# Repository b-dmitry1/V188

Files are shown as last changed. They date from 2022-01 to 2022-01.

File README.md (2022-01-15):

# V188

FPGA 80186 IBM PC compatible system for Altera Cyclone IV (EP4CE15F23/EP4CE55F23).

* Compact CPU implementation (CPU can fit in 1500-2300 LEs and 4-6 M9K ROM blocks!).
* Easy-to-understand extensible FPGA-accelerated microcode.
* Inexpensive 4-layer PCB.
* A minimal set of inexpensive external components is required. All the electronic components can be easily found on AliExpress or eBay.
* Can be used with lower capacity FPGA devices if you don't need music in games.
* Up to 50 MHz input clock speed.

The CPU is a simple **stack virtual machine** with a specialized reduced instruction set.

Execution algorithm:

1. The VM fetches an opcode from system memory pointed by CS:IP.
2. There is a table of instruction code locations at the beginning of a microcode file. Using a loaded opcode value the VM starts processing microcode by table-jumping.
3. VM emulates real CPU behavior by sequentially executing microcode instructions.
4. When END microcode instruction is executed VM resets temporary state registers and instruction prefixes, checks pending interrupt requests, and repeats the algorithm from step 1.

Microcode example for table translation (XLAT) instruction:

```assembly
; xlat
LOADREG BX      ; Push BX register into VM stack
LOADREG8 AL     ; Push AL register into VM stack
ADD             ; Add two values on the top of VM stack and push back the result
SETOFS          ; Save value on the top of VM stack as a memory address (offset)
READ8           ; Read 8-bit value from system RAM pointed by the data segment register
                ; and an address saved in a previous instruction
                ; Data segment register is DS unless overridden by instruction prefix
STOREREG8 AL    ; Save the result into AL register
END             ; Go to a next instruction
```

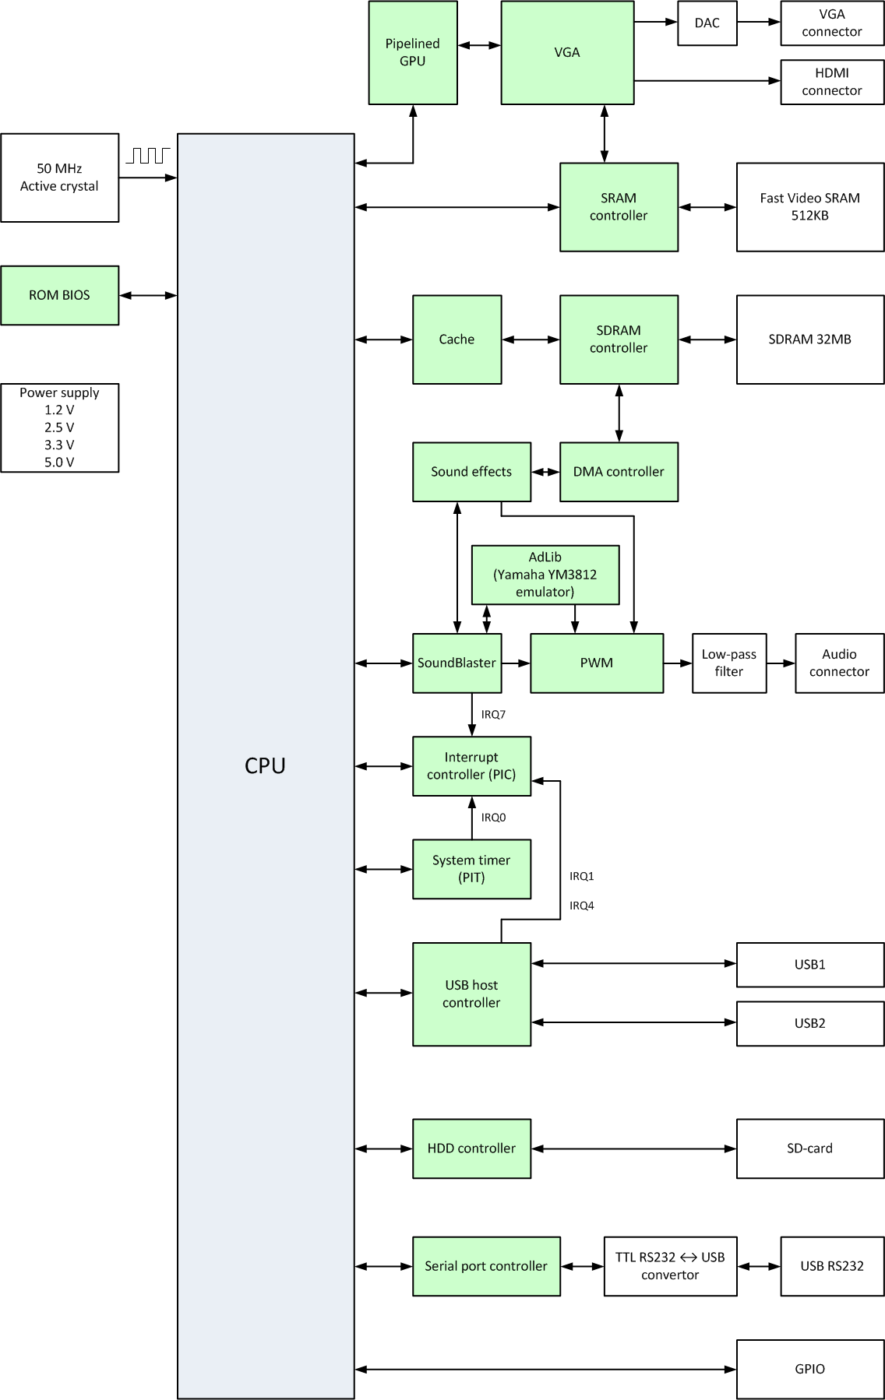
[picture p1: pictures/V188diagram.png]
V188 diagram


To play Dune 2 and Wolfenstein 3D just enable 286 CPU detection in the mcode.asm file:

    %define SHOW_8086

Comment this line, compile and update the project firmware. This line should be uncommented if you want to run Windows or Minix in 16-bit real mode.

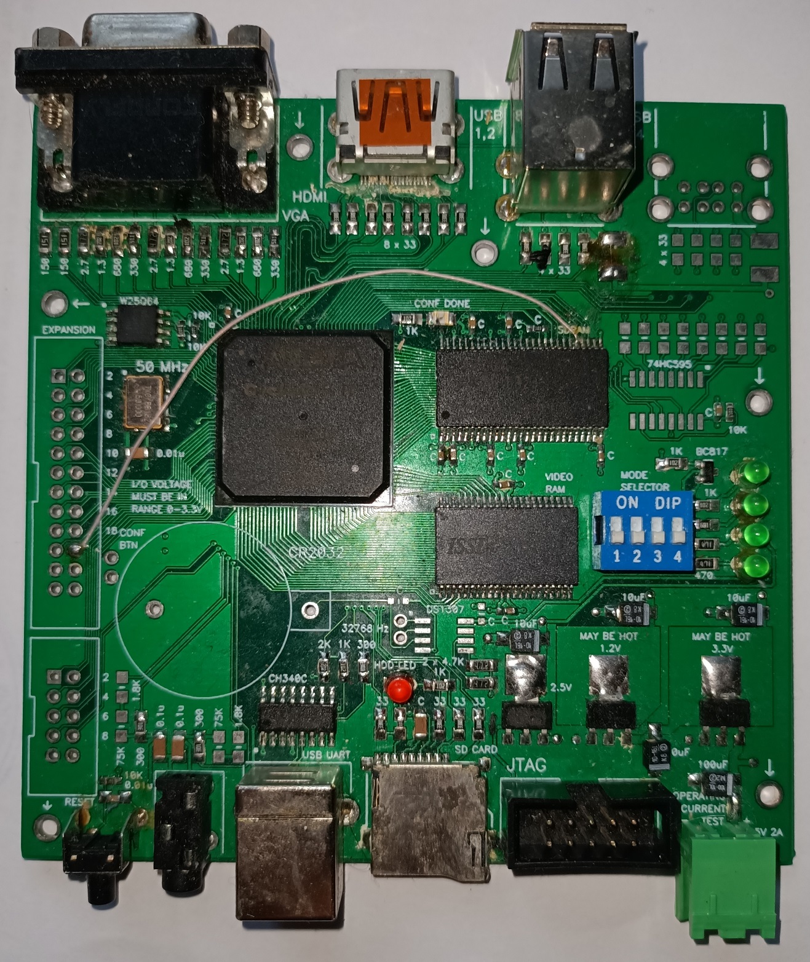
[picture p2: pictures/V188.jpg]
V188


## Printed circuit board (PCB)

PCB Gerber files can be found in a [Gerber directory](Gerber/).

## BIOS

Please use this compact BIOS:

<https://github.com/b-dmitry1/BIOS>

## VGA

* CGA/EGA/VGA video card emulation.
* Linear / Planar addressing support.
* Simple EGA/VGA graphics processor (pipeline) compatible with most old games and Microsoft Windows.
* Planar 320x240x256 colors (mode X) support.
* 2 x 64-bit GPU data buses designed to unload RAM controller.
* The framebuffer can be located in the main system memory or in a dedicated video RAM.

## SoundBlaster

* 8-bit digital sound effects with DMA support.
* Unprecise but very simple extensible AdLib emulation.
* High-quality PWM output requires only 1-2 resistors and 1 ceramic capacitor.

AdLib consumes a lot of FPGA resources. Precise YM3812 emulation may require 30K LEs or even more.

## SDRAM controller

* Very simple and compact finite state machine design.
* Multiple channels. Additional channels can be easily added.
* Channel priorites defined by their order.
* Different bus widths.
* Automatic SDRAM refresh.
* Designed for a low-cost 16/32 megabyte SDRAM ICs.

## Memory card interface

Up to 32GB memory card with SPI support can be used.

Only 504 MB will be available due to 16-bit BIOS's limitations.

## USB

This version contains a new USB module with a dedicated parallel processing core designed to operate independently from a main CPU.
Firmware for this fast module is not completed.
Please use an old implementation from deprecated/USB folder or a Serial Port as a keyboard.

There are 4 USB ports on the board.
In this version only 2 low-speed ports are available.
The first one should be used for a keyboard and the second one for mouse.

USB needs a special BIOS driver to work properly.

## Compiling

Please use Quartus 13.0sp1 to compile the project.

To compile from a command line use "compile.bat" script.

## Disk images

Images from [e86r project](https://github.com/b-dmitry1/e86r) will work good.

Just write an 504 MB image on an SD card as described in the STM32 section of e86r.

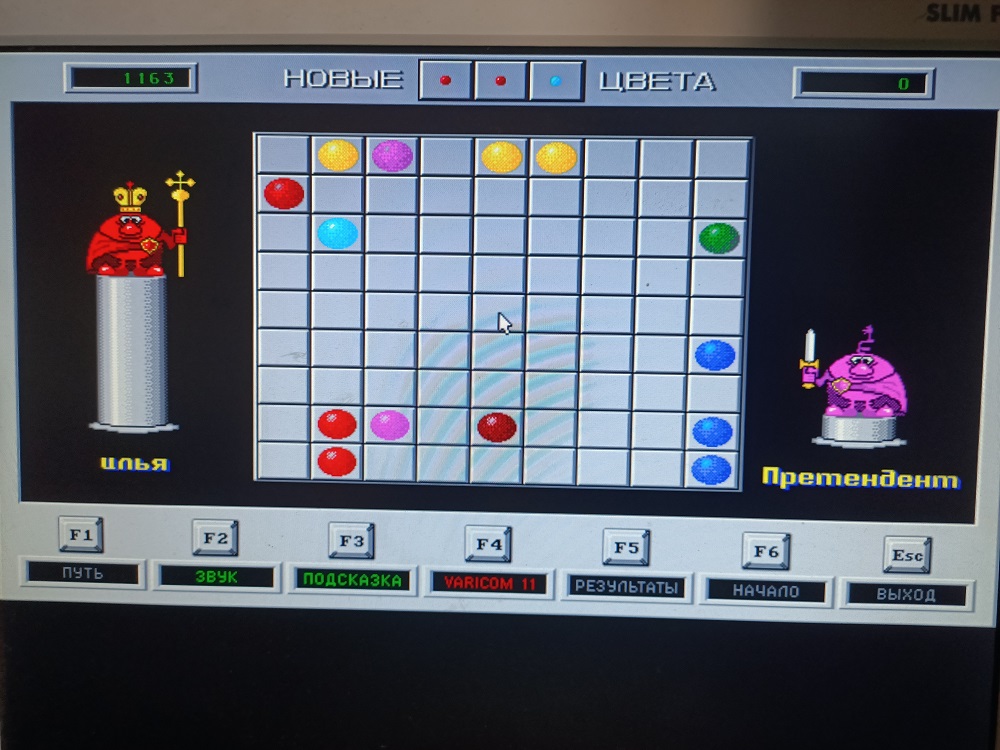
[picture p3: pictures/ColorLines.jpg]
Lines game screenshot


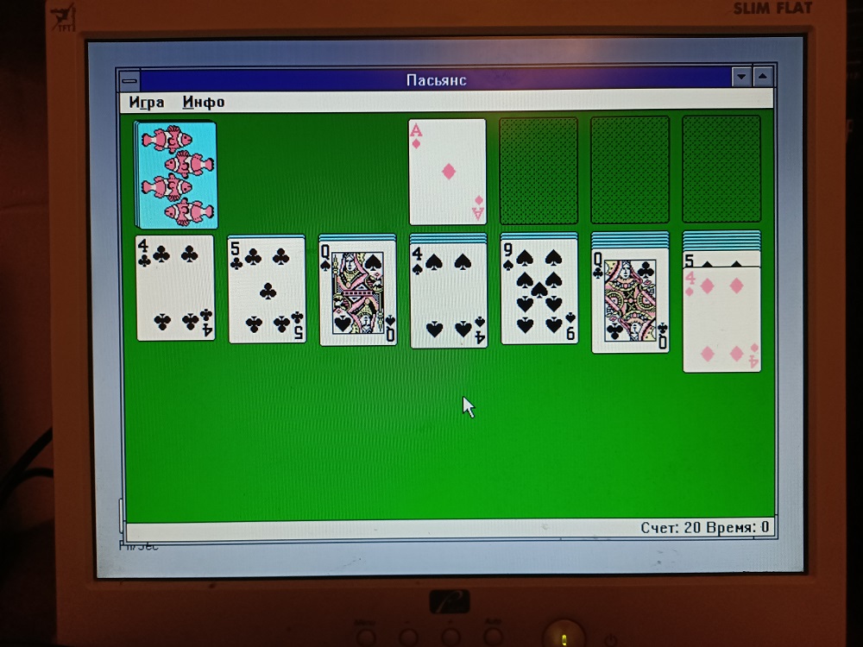
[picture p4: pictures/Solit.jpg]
Solitare game screenshot


## Known problems

* USB detection / hot plugging sometimes fails.
* USB port 1 supports only a keyboard and port 2 supports only a mouse. (BIOS problem)
* Only low-speed USB device support.
* VGA virtual resolution (panning) calculation may be wrong for some games.
* No FPU emulation.

## Disclaimer

The project is provided "as is" without any warranty. Use at your own risk.

Please contact me if you find any bug or if you plan to port it to another platform.

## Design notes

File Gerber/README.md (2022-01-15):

# V188 Gerber files

This folder contains Gerber PCB files of the board.

Technology:

* 4 layers.
* Minimum hole diameter is 0.3 mm.
* Via diameter is 0.6 mm.
* Track width min 0.127 mm.
* Track-to-pad min 0.127 mm.
* Track-to-track min 0.127 mm.

Most popular PCB factories should accept it without applying a price multiplier.

I have paid only $7 for 5 pcs on jlcpcb.com

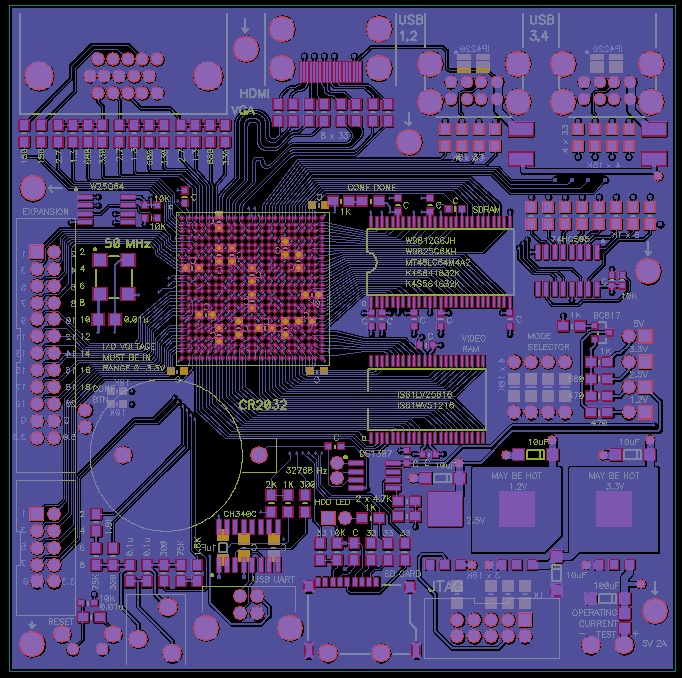
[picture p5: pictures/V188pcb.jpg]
V188 PCB


ICs:

* EP4CE55F23C8N - FPGA
* W25Q64 - Configuration EEPROM
* W9825G6KHC1 - SDRAM
* IS61LV25616 - Video SRAM
* CH340C - Debug UART to USB
* AMS1117-3.3 - 3.3 V power converter
* AMS1117-2.5 - 2.5 V power converter
* AMS1117-1.2 - 1.2 V power converter
* 50 MHz active crystal generator

Please do not connect 5 V ICs/devices directly to FPGA!

Refer to Cyclone IV datasheet for voltage overshoot diagrams.

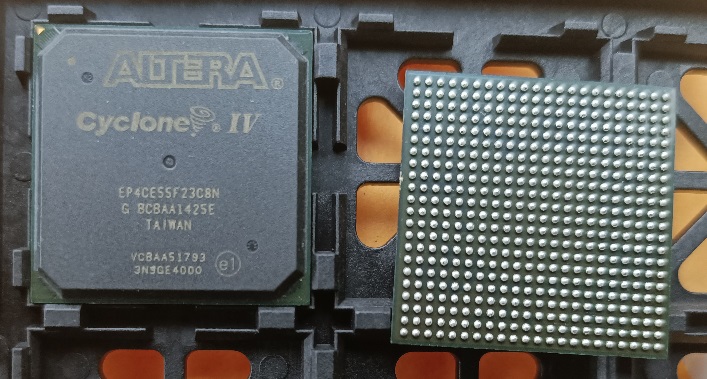
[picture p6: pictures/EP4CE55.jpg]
Cyclone IV EP4CE55 chips


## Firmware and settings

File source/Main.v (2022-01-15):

module Main(
	input wire clk,
	input wire reset_n,
	
	output wire led,
	
	// VGA
	output wire hsync,
	output wire vsync,
	
	output wire [3:0] red,
	output wire [3:0] green,
	output wire [3:0] blue,
	
	// HDMI
	output wire hdmi_rp,
	output wire hdmi_rm,
	output wire hdmi_gp,
	output wire hdmi_gm,
	output wire hdmi_bp,
	output wire hdmi_bm,
	output wire hdmi_cp,
	output wire hdmi_cm,
	
	// Audio
	output wire [1:0] audio_left,
	output wire [1:0] audio_right,
	
	// SDRAM
	output wire [12:0] sdram_a,
	output wire [1:0] sdram_ba,
	inout wire [15:0] sdram_d,
	output wire [1:0] sdram_dqm_n,
	output wire sdram_ras_n,
	output wire sdram_cas_n,
	output wire sdram_we_n,
	output wire sdram_cs_n,
	output wire sdram_sclk,
	output wire sdram_scke,
	
	// SRAM
	output wire [17:0] ram_a,
	inout wire [15:0] ram_d,
	output wire ram_cs_n,
	output wire ram_we_n,
	output wire ram_oe_n,
	output wire ram_lb_n,
	output wire ram_ub_n,
	
	// HC595 / leds
	output reg clk595,
	output wire dat595,
	output reg lat595,
	
	// SD-card
	output wire sd_cs_n,
	output wire sd_mosi,
	input wire sd_miso,
	output wire sd_sck,
	
	// USB
	inout wire dm1,
	inout wire dp1,
	inout wire dm2,
	inout wire dp2,
	
	// RS232
	input wire ch_txd,
	output wire ch_rxd
);

wire clk2;

assign ch_rxd = com1txd;

assign com1rxd = ch_txd;

localparam
	S_IDLE = 3'd0,
	S_MREAD = 3'd1,
	S_MWRITE = 3'd2,
	S_IOREAD = 3'd3,
	S_IOWRITE = 3'd4,
	S_IOREAD2 = 3'd5;

reg [2:0] state;

reg [27:0] div;

assign led = com1txd;

reg [7:0] keyb_ctrl;

////////////////////////////////////////////////////////////////////////////////////////////////////////////////////
// DMA
////////////////////////////////////////////////////////////////////////////////////////////////////////////////////
wire [23:0] dma1_addr;
wire [7:0] dma1_din;
wire dma1_rdin;
wire dma1_rdout;
wire [7:0] dma1_dout;
wire dma1_wrin;
wire dma1_wrout;
wire irq7;
DMA8 dma1(
	.clk(clk),
	.reset_n(reset_n),
	.port(port),
	.iodin(ciodout),
	.iowrin(ciowrout),
	
	.dma1_addr(dma1_addr),
	.dma1_din(dma1_din),
	.dma1_rdin(dma1_rdin),
	.dma1_rdout(dma1_rdout),
	
	.dma1_dout(dma1_dout),
	.dma1_wrin(dma1_wrin),
	.dma1_wrout(dma1_wrout),
	
	.irq7(irq7)
);

////////////////////////////////////////////////////////////////////////////////////////////////////////////////////
// Fake AdLib
////////////////////////////////////////////////////////////////////////////////////////////////////////////////////
wire [7:0] adlib_iodout;
wire adlib_ready;
wire [7:0] music;
AdLib adlib(
	.clk(clk),
	.reset_n(reset_n),
	
	.port(port),
	.iodin(ciodout),
	.iodout(adlib_iodout),
	.iowr(iowr),
	.ready(adlib_ready),
	
	.music(music)
);

////////////////////////////////////////////////////////////////////////////////////////////////////////////////////
// SoundBlaster
////////////////////////////////////////////////////////////////////////////////////////////////////////////////////
assign audio_left = 2'b00;//pwm_left ? 2'b11 : 2'b00;
assign audio_right = {2{keyb_ctrl[1] && ((~keyb_ctrl[0]) | t2out) && (&speaker_pwm)}};

reg [1:0] speaker_pwm;

always @(posedge clk)
	speaker_pwm <= speaker_pwm + 1'd1;

wire [7:0] sb_iodout;
wire pwm_left;
SoundBlaster sb(
	.clk(clk),
	.reset_n(reset_n),
	
	.port(port),
	.iodin(ciodout),
	.iodout(sb_iodout),
	.iowrin(ciowrout),
	.iordin(ciordout),
	
	.dma_din(dma1_dout),
	.dma_rdin(dma1_wrout),
	.dma_rdout(dma1_wrin),
	
	.adlib_in(music),
	
	.pwm_left(pwm_left)
);

////////////////////////////////////////////////////////////////////////////////////////////////////////////////////
// PLL
////////////////////////////////////////////////////////////////////////////////////////////////////////////////////
wire clk250;
wire clk_sdram;
wire clk_sram;
PLL1 pll1(.inclk0(clk), .c0(clk_sdram), .c1(clk250), .c2(clk_sram), .c3(clk2));

wire clk60;
PLL2 pll2(.inclk0(clk), .c0(clk60));

////////////////////////////////////////////////////////////////////////////////////////////////////////////////////
// HC595
////////////////////////////////////////////////////////////////////////////////////////////////////////////////////
reg [7:0] data595;
reg [16:0] state595;
reg [7:0] shift595;

assign dat595 = shift595[7];

////////////////////////////////////////////////////////////////////////////////////////////////////////////////////
// SDRAM
////////////////////////////////////////////////////////////////////////////////////////////////////////////////////
wire [7:0] cpu_dout_sdram;
reg [7:0] cpu_din_sdram;
wire cpu_rdin_sdram;
reg  cpu_rdout_sdram;
wire cpu_wrin_sdram;
reg cpu_wrout_sdram;
wire sdram_cpu_addr_hit;

SDRAM sdram(.clk(clk), .clk1(clk_sdram), .reset_n(reset_n),
	.cpu_addr(ca), .cpu_din(cdout), .cpu_dout(cpu_dout_sdram), .cpu_addr_hit(sdram_cpu_addr_hit),
	.cpu_rdin(cpu_rdout_sdram), .cpu_rdout(cpu_rdin_sdram), .cpu_wrin(cpu_wrout_sdram), .cpu_wrout(cpu_wrin_sdram),

	.dma_addr(dma1_addr),
	.dma_dout(dma1_din),
	.dma_rdin(dma1_rdout),
	.dma_rdout(dma1_rdin),

	/*
	.video_addr(video_addr[23:3]), .video_dout(video_din),
	
	.gpu_addr(gpu_addr),
	.gpu_din(gpu_din),
	.gpu_dout(gpu_dout),
	.gpu_rdin(gpu_rdin),
	.gpu_rdout(gpu_rdout),
	.gpu_wrin(gpu_wrin),
	.gpu_wrout(gpu_wrout),
	*/
	
	.a(sdram_a), .ba(sdram_ba), .d(sdram_d), .ras_n(sdram_ras_n), .cas_n(sdram_cas_n), .we_n(sdram_we_n), .cs_n(sdram_cs_n),
	.sclk(sdram_sclk), .scke(sdram_scke), .dqm(sdram_dqm_n));

	
////////////////////////////////////////////////////////////////////////////////////////////////////////////////////
// SRAM
////////////////////////////////////////////////////////////////////////////////////////////////////////////////////
wire [7:0] cpu_dout_sram;
reg [7:0] cpu_din_sram;
wire cpu_rdin_sram;
reg  cpu_rdout_sram;
wire cpu_wrin_sram;
reg cpu_wrout_sram;

wire [23:0] gpu_addr;
wire [31:0] gpu_din;
wire [31:0] gpu_dout;
wire gpu_rdin;
wire gpu_rdout;
wire gpu_wrin;
wire gpu_wrout;

SRAM sram(.clk(clk_sram),
	.cpu_addr(ca), .cpu_din(cdout), .cpu_dout(cpu_dout_sram),
	.cpu_rdin(cpu_rdout_sram), .cpu_rdout(cpu_rdin_sram), .cpu_wrin(cpu_wrout_sram), .cpu_wrout(cpu_wrin_sram),
	.gpu_addr(gpu_addr), .gpu_din(gpu_din), .gpu_dout(gpu_dout),
	.gpu_rdin(gpu_rdin), .gpu_rdout(gpu_rdout), .gpu_wrin(gpu_wrin), .gpu_wrout(gpu_wrout),
	.video_addr(video_addr), .video_dout(video_din),
	.a(ram_a), .d(ram_d), .we_n(ram_we_n), .cs_n(ram_cs_n), .oe_n(ram_oe_n),
	.lb_n(ram_lb_n), .ub_n(ram_ub_n));
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

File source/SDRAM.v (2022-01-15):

module SDRAM(
	input wire clk,
	input wire clk1,
	input wire reset_n,

	output wire ready,
	output wire cpu_addr_hit,
	
	input wire [24:0] cpu_addr,
	input wire [7:0] cpu_din,
	output wire [7:0] cpu_dout,
	input wire cpu_rdin,
	output reg cpu_rdout,
	input wire cpu_wrin,
	output reg cpu_wrout,

	input wire [24:0] dma_addr,
	output reg [7:0] dma_dout,
	input wire dma_rdin,
	output reg dma_rdout,

	output reg [12:0] a,
	output reg [1:0] ba,
	output reg [1:0] dqm,
	inout wire [15:0] d,
	output wire ras_n,
	output wire cas_n,
	output wire we_n,
	output wire cs_n,
	output wire sclk,
	output reg scke
);

/*
assign cs_n = 1'b1;

reg [23:0] div;

always @(posedge clk)
begin
	div <= div + 24'd1;
end

always @(negedge div[23])
	a <= |a ? {a[0], a[12:1]} : 13'd1;
*/

// col 9 + row 12 + ba 2 = 23 = 8 MB
// 8 MB x 4 = 32 MB

// row = 9 + 2 = 11 = 2 KB


assign d =
	state == S_WRITE_CPU ? {2{cpu_din}} :
	16'hZZZZ;

reg [24:2] cpu_data_addr;
reg [31:0] cpu_data;
reg cpu_data_valid;

assign cpu_dout =
	cpu_addr[1:0] == 2'b00 ? cpu_data[7:0] :
	cpu_addr[1:0] == 2'b01 ? cpu_data[15:8] :
	cpu_addr[1:0] == 2'b10 ? cpu_data[23:16] :
	cpu_data[31:24];
	
assign cpu_addr_hit = (cpu_data_addr == cpu_addr[24:2]) && cpu_data_valid;

reg [19:0] start;
reg start1, start2, start3;
always @(posedge clk or negedge reset_n)
begin
	if (~reset_n)
		start <= 20'd0;
	else
		start <= start[19] ? start : start + 20'd1;
end
always @(posedge clk)
begin
	start3 = start[19];
	start2 = |start[19:18];
	start1 = |start[19:17];
end

localparam S_START 						= 0;
localparam S_IDLE 						= 1;
localparam S_PRECHARGE		 			= 2;
localparam S_LOADMODE 					= 3;
localparam S_READ_CPU					= 4;
localparam S_READ_CPU_1					= 5;
localparam S_READ_CPU_2					= 6;
localparam S_READ_CPU_3					= 7;
localparam S_WRITE_CPU					= 8;
localparam S_WRITE_CPU_1				= 9;
localparam S_WRITE_CPU_2				= 10;
localparam S_REFRESH 					= 11;
localparam S_REFRESH_1 					= 12;
localparam S_REFRESH_2 					= 13;
localparam S_REFRESH_3 					= 14;
localparam S_REFRESH_DONE 				= 15;
localparam
	S_READ_DMA								= 16,
	S_READ_DMA_1							= 17,
	S_READ_DMA_2							= 18;

												//   SRCW
localparam NOP								= 4'b0000;
localparam PRECHARGE						= 4'b1101;
localparam REFRESH						= 4'b1110;
localparam LOADMODE						= 4'b1111;
localparam ACTIVE							= 4'b1100;
localparam READ							= 4'b1010;
localparam WRITE							= 4'b1011;

reg [4:0] state;

reg [9:0] refresh;

reg [3:0] cmd;

assign sclk = clk1;

assign cs_n = ~cmd[3];
assign ras_n = ~cmd[2];
assign cas_n = ~cmd[1];
assign we_n = ~cmd[0];

reg [13:0] row;
reg row_active;

assign ready = (cpu_rdin == cpu_rdout) && (cpu_wrin == cpu_wrout);

always @(posedge clk)
begin
	scke <= start1;
	
	refresh <= state == S_REFRESH ? 10'd0 : refresh + 10'd1;
end

always @(posedge clk or negedge reset_n)
begin
	if (~reset_n)
	begin
		state <= S_START;
	end
	else
	begin
		case (state)
			S_START:
			begin
				cmd <= NOP;
				ba <= 2'b00;
				if (start2)
					state <= S_IDLE;
				cpu_data_valid <= 1'b0;
				row_active <= 1'b0;
			end
			S_IDLE:
			begin
				if (~start3)
				begin
				end
				else if (refresh[8])
				begin
					cmd <= PRECHARGE;
					a <= 13'h400;
					ba <= 2'b00;
					row_active <= 1'b0;
					state <= S_REFRESH;
				end
				else if (dma_rdin ^ dma_rdout)
				begin
					dqm <= 2'b00;
					if (row_active)
					begin
						if (row == dma_addr[23:10])
						begin
							state <= S_READ_DMA;
						end
						else
						begin
							cmd <= PRECHARGE;
							a <= 13'h400;
							ba <= 2'b00;
							row_active <= 1'b0;
						end
					end
					else
					begin
						cmd <= ACTIVE;
						a <= dma_addr[21:10];
						ba <= dma_addr[23:22];
						row <= dma_addr[23:10];
						row_active <= 1'b1;
						state <= S_READ_DMA;
					end
				end
				else if (cpu_rdin ^ cpu_rdout)
				begin
					dqm <= 2'b00;
					if (row_active)
					begin
						if (row == cpu_addr[23:10])
						begin
							state <= S_READ_CPU;
						end
						else
						begin
							cmd <= PRECHARGE;
							a <= 13'h400;
							ba <= 2'b00;
							row_active <= 1'b0;
						end
					end
					else
					begin
						cmd <= ACTIVE;
						a <= cpu_addr[21:10];
						ba <= cpu_addr[23:22];
						row <= cpu_addr[23:10];
						row_active <= 1'b1;
						state <= S_READ_CPU;
					end
				end
				else if (cpu_wrin ^ cpu_wrout)
				begin
					dqm[0] <= cpu_addr[0] != 1'b0;
					dqm[1] <= cpu_addr[0] != 1'b1;
					if (row_active)
					begin
						if (row == cpu_addr[23:10])
						begin
							state <= S_WRITE_CPU;
						end
						else
						begin
							cmd <= PRECHARGE;
							a <= 13'h400;
							ba <= 2'b00;
							row_active <= 1'b0;
						end
					end
					else
					begin
						cmd <= ACTIVE;
						a <= cpu_addr[21:10];
						ba <= cpu_addr[23:22];
						row <= cpu_addr[23:10];
						row_active <= 1'b1;
						state <= S_WRITE_CPU;
					end
				end
			end
			S_REFRESH:
			begin
				cmd <= REFRESH;
				state <= S_REFRESH_1;
			end
			S_REFRESH_1:
			begin
				cmd <= NOP;
				state <= S_REFRESH_2;
			end
			S_REFRESH_2:
				state <= S_REFRESH_3;
			S_REFRESH_3:
				state <= S_REFRESH_DONE;
			S_REFRESH_DONE:
			begin
				cmd <= LOADMODE;
				a <= 13'h220;
				ba <= 2'b00;
				state <= S_LOADMODE;
			end
			S_LOADMODE:
			begin
				cmd <= NOP;
				state <= S_IDLE;
			end
			S_READ_DMA:
			begin
				cmd <= READ;
				a <= {4'b00, dma_addr[9:1]};
				ba <= dma_addr[23:22];
				state <= S_READ_DMA_1;
			end
			S_READ_DMA_1:
			begin
				cmd <= NOP;
				state <= S_READ_DMA_2;
			end
			S_READ_DMA_2:
			begin
				dma_dout <= dma_addr[0] ? d[15:8] : d[7:0];
				dma_rdout <= ~dma_rdout;
				state <= S_IDLE;
			end
			S_READ_CPU:
			begin
				cmd <= READ;
				a <= {4'b00, cpu_addr[9:2], 1'b0};
				ba <= cpu_addr[23:22];
				state <= S_READ_CPU_1;
			end
			S_READ_CPU_1:
			begin
				a <= {4'b00, cpu_addr[9:2], 1'b1};
				state <= S_READ_CPU_2;
			end
			S_READ_CPU_2:
			begin
				cmd <= NOP;
				cpu_data[15:0] <= d[15:0];
				state <= S_READ_CPU_3;
			end
			S_READ_CPU_3:
			begin
				cpu_data_addr <= cpu_addr[24:2];
				cpu_data[31:16] <= d[15:0];
				cpu_data_valid <= 1'b1;
				cpu_rdout <= ~cpu_rdout;
				state <= S_IDLE;
			end
			S_WRITE_CPU:
			begin
				if (cpu_addr[24:2] == cpu_data_addr)
				begin
					cpu_data[7:0] <= cpu_addr[1:0] == 2'd0 ? cpu_din : cpu_data[7:0];
					cpu_data[15:8] <= cpu_addr[1:0] == 2'd1 ? cpu_din : cpu_data[15:8];
					cpu_data[23:16] <= cpu_addr[1:0] == 2'd2 ? cpu_din : cpu_data[23:16];
					cpu_data[31:24] <= cpu_addr[1:0] == 2'd3 ? cpu_din : cpu_data[31:24];
				end
				cmd <= WRITE;
				a <= {4'b00, cpu_addr[9:1]};
				state <= S_WRITE_CPU_1;
			end
			S_WRITE_CPU_1:
			begin
				cmd <= NOP;
				dqm <= 2'b00;
				cpu_wrout <= ~cpu_wrout;
				state <= S_IDLE;
			end
			default:
				state <= S_START;
		endcase
	end
end

endmodule
